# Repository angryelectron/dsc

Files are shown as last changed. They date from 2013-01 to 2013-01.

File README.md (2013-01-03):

The DSC is an Arduino-based differential solar controller.  Please visit
http://angryelectron.com/projects/dsc for more information.

Here you will find Eagle project files for the schematic and PCB, the DSC
firmware (Arduino sketch), a Google Gadget, and some Bash scripts that can be
used for monitoring.

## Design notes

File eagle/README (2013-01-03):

This is a CadSoft Eagle project for the DSC schematic capture and PCB layout. 

Set your Eagle project directory to this one for easy access to projects,
libraries, scripts, and design rules within the Eagle IDE.

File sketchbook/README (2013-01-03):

This is the firmware (Arduino sketch) for the DSC controller. Please see
http://angryelectron.com/projects/dsc for more information.

Set your Arduino IDE Sketchbook directory to this one to automatically include
the dependent libraries (DallasTemperature and OneWire), if you don't have them
installed elsewhere.

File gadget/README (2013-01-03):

This is a Google Gadget for displaying the output temperatures of the DSC.

Place gsolar.xml and screenshot.png on a webserver and update the URLS in
gsolar.xml to match.  Data for the gadget is taken from 'solar.xml', which is
produced by the dsc-monitor.sh script.

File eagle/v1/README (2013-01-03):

These are the Gerber files that were uploaded to BatchPCB to create the DSC
PCB.  View it here: https://batchpcb.com/pcbs/27415

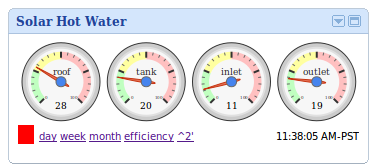
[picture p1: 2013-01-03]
gadget/screenshot.png

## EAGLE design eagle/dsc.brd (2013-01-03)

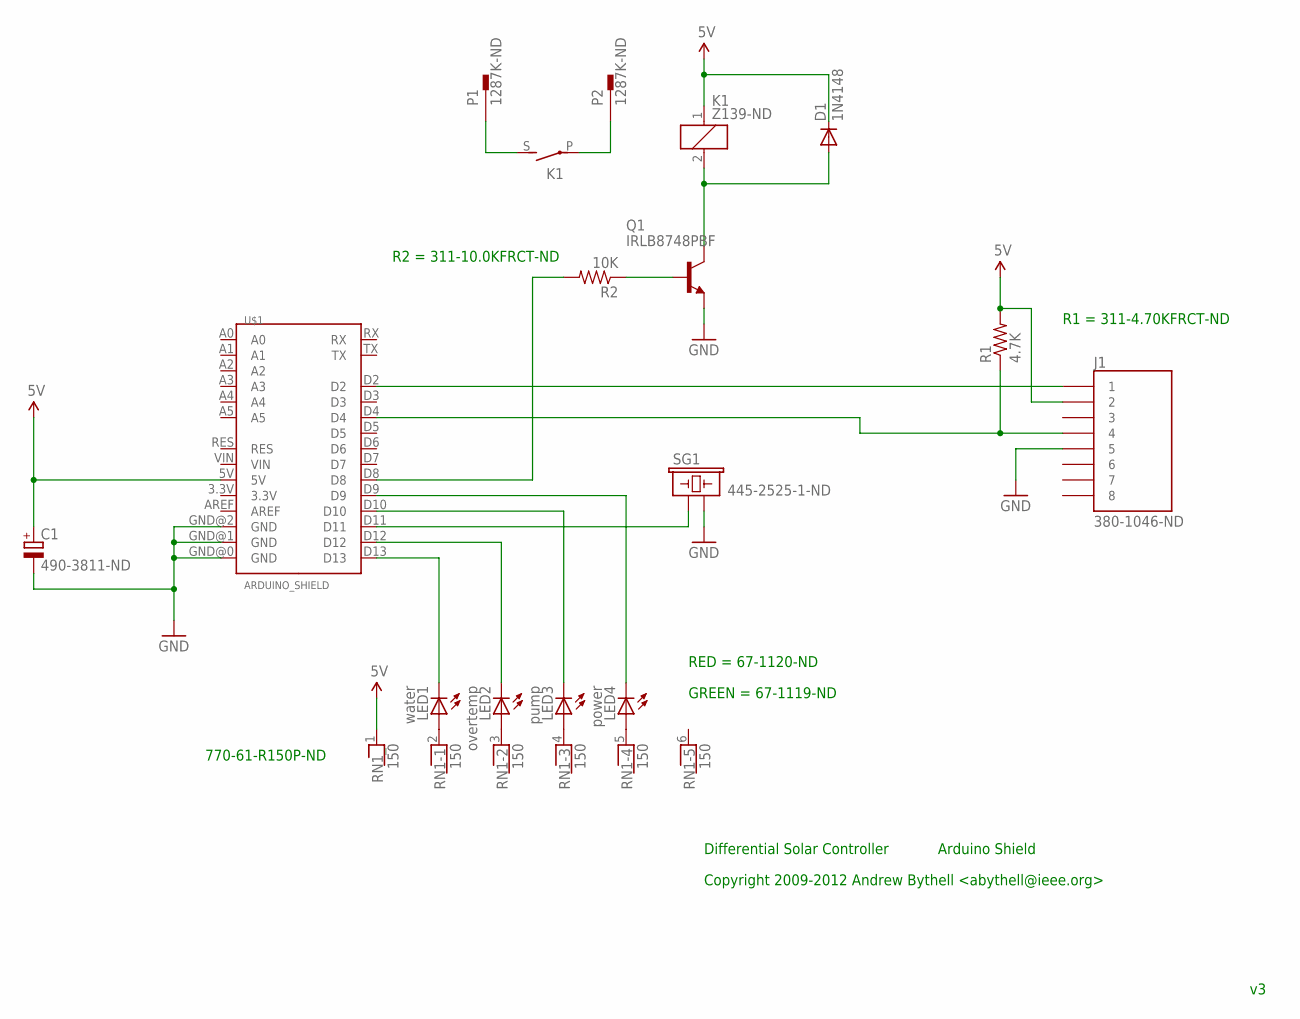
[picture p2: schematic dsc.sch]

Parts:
C1: 490-3811-ND; E3,5-8
D1: 1N4148; DO35-10
J1: 380-1046-ND; RJ45-8
K1: Z139-ND; G2RA
LED1: water; LED5MM
LED2: overtemp; LED5MM
LED3: pump; LED5MM
LED4: power; LED5MM
P1, P2: 1287K-ND; F061.100
Q1: IRLB8748PBF; TO18
R1: 4.7K; 1206
R2: 10K; 1206
RN1: 150; RN-6
SG1: 445-2525-1-ND; BUZZER-12MM-AB
U$1: ARDUINO_SHIELD; DUEMILANOVE_SHIELD

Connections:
5V: C1.+, D1.C, J1.2, K1.1, R1.2, RN1.1, U$1.5V
ERASE: J1.4, R1.1, U$1.D4
GND: C1.-, J1.5, Q1.1 (E), SG1.- (2), U$1.GND@0 (GND), U$1.GND@1 (GND), U$1.GND@2 (GND)
unnamed: Q1.2 (B), R2.1
unnamed: R2.2, U$1.D8
unnamed: D1.A, K1.2, Q1.3 (C)
unnamed: LED1.A, RN1.2
unnamed: LED2.A, RN1.3
unnamed: LED3.A, RN1.4
unnamed: LED4.A, RN1.5
unnamed: LED1.K (C), U$1.D13
unnamed: LED2.K (C), U$1.D12
unnamed: LED3.K (C), U$1.D10
unnamed: LED4.K (C), U$1.D9
unnamed: SG1.+ (1), U$1.D11
unnamed: K1.S, P1.A1, P1.A2
unnamed: K1.P, P2.A1, P2.A2
unnamed: J1.1, U$1.D2

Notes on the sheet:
Differential Solar Controller
Arduino Shield
770-61-R150P-ND
RED = 67-1120-ND
GREEN = 67-1119-ND
R1 = 311-4.70KFRCT-ND
R2 = 311-10.0KFRCT-ND
Copyright 2009-2012 Andrew Bythell <abythell@ieee.org>

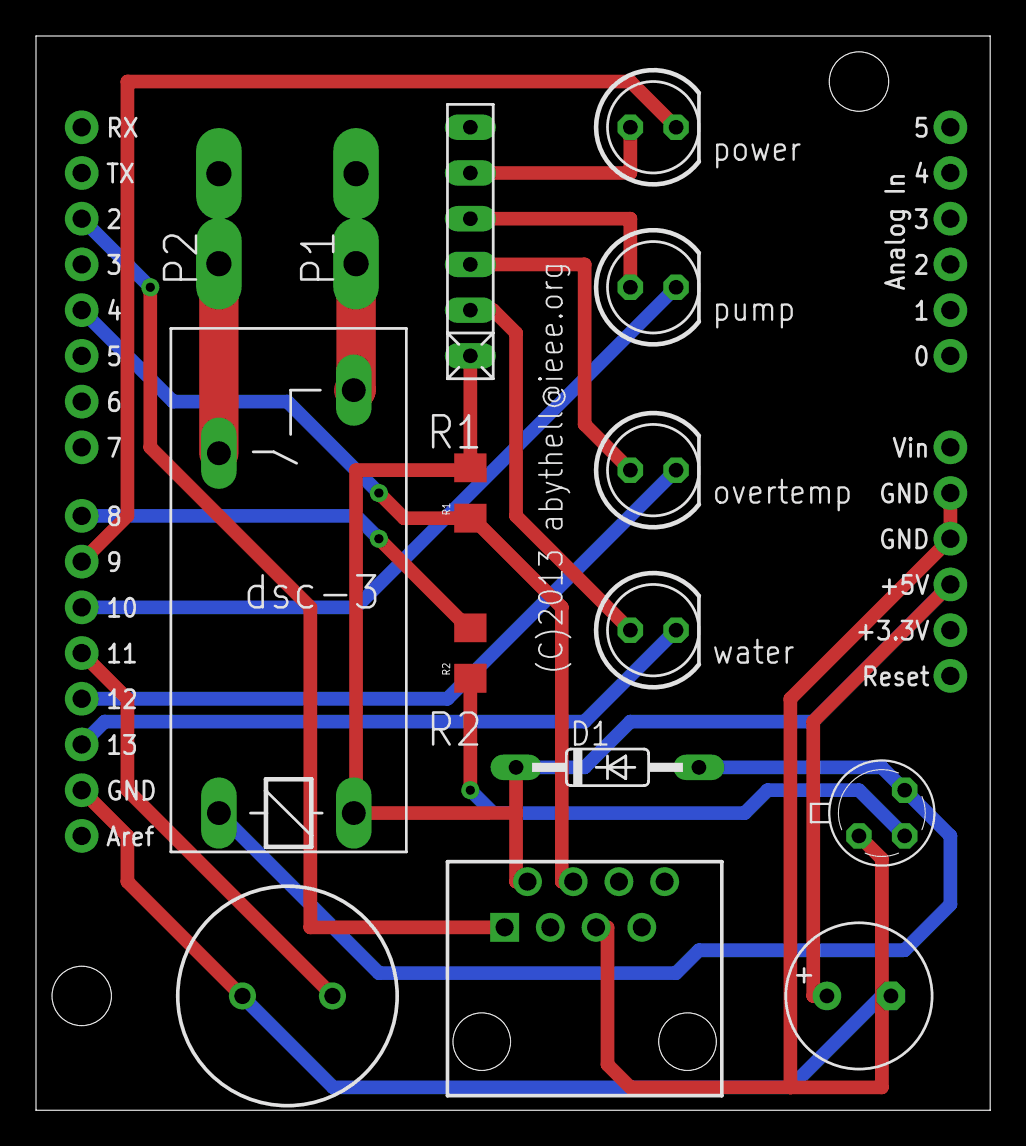
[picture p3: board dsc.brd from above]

Board: 2 copper layers, 53.0 x 59.7 mm, 16 parts (0 on the bottom side), 18 nets.

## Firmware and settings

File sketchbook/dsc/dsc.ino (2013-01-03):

/*
  Differential Solar Controller for Arduino 1.0
  Copyright 2009-2012 Andrew Bythell <abythell@ieee.org>

  This sketch depends on the Dallas Temperature Control Library (milesburton.com/Dallas_Temperature_Control_Library)
  version 3.7.2, and the OneWire 2 Library (pjrc.com/teensy/td_libs_OneWire.html) version 2.1.

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
  You should have received a copy of the GNU General Public License
  along with this program.  If not, see <http://www.gnu.org/licenses/>.
*/

#include <OneWire.h>
#include <DallasTemperature.h>
#include "dsc.h"

/*
 * Setup
 */
void setup(void) 
{
  	pinMode(PUMP_LED, OUTPUT);
        pinMode(PUMP_RELAY, OUTPUT);
	pinMode(POWER_LED, OUTPUT);
	pinMode(OVERTEMP_LED, OUTPUT);
	pinMode(WATER_LED, OUTPUT);
	pinMode(ALARM_PIN, OUTPUT);
	pinMode(WATER_SENSOR, INPUT);

	Serial.begin(9600);
        sensors.begin();
	POWER_ON;
        PUMP_OFF;
	OVERTEMP_OFF;
	ALARM_OFF;
	FAULT_OFF;
	WATER_OFF;
}

/*
 * Check for Low Water Level Condition
 */
void CheckWaterLevel()
{
	if (WATER_LOW)
	{
                PUMP_OFF;
		WATER_ON;
		state = LOWWATER_STATE; 
	}
}

/*
 * Stop State
 */
void StopState()
{
	if (sensors.getTempC(roofSensor) >= sensors.getTempC(tankSensor) + DELTA_ON)
	{
		PUMP_ON;
		state = RUN_STATE;
	}
}

/*
 * Run State
 */
void RunState()
{
	if (sensors.getTempC(tankSensor) >= HIGHTEMP_LIMIT)
	{
		PUMP_OFF;
		OVERTEMP_ON;
		state = OVERTEMP_STATE;
	}
	else if (sensors.getTempC(tankSensor) + DELTA_OFF >= sensors.getTempC(roofSensor))
	{
		PUMP_OFF;
		state = STOP_STATE;  
	}
}

/*
 * Over Temperature State
 */
void OverTempState()
{
	if ((sensors.getTempC(tankSensor) + DELTA_OFF >= sensors.getTempC(roofSensor))
          || (sensors.getTempC(tankSensor) <= OVERTEMP_LIMIT))
	{
		PUMP_OFF;
                OVERTEMP_OFF;
		state = STOP_STATE;  
	}
}

/*
 * Low Water State - Remain in Low Water State until the level is topped up.
 */
void LowWaterState()
{
	if (!WATER_LOW)
	{
		WATER_OFF;
		state = STOP_STATE;
	}
}

/*
 * Print Status to serial port for data logging
 */
void PrintStatus()
{
	uint8_t roofTemp = sensors.getTempC(roofSensor);
	uint8_t tankTemp = sensors.getTempC(tankSensor);
	uint8_t inletTemp = sensors.getTempC(inletSensor);
	uint8_t outletTemp = sensors.getTempC(outletSensor);
	char ascii[10];
	sprintf(ascii, "%02x %02x %02x %02x %02x", state, roofTemp, tankTemp, inletTemp, outletTemp);
	Serial.println(ascii);
}

/*
 * Loop
 */
void loop(void) 
{
    sensors.requestTemperatures();
    
    /*
     * Wait for temperature conversion to complete
     */
    delay(1000);
    
    CheckWaterLevel();
    switch(state)
    {
	case STOP_STATE:
		StopState();
		break;
	case RUN_STATE:
		RunState();
		break;
	case OVERTEMP_STATE:
		OverTempState();
		break;
	case LOWWATER_STATE:
		LowWaterState();
		break;
	default:
                break;
    } 
    PrintStatus();
}

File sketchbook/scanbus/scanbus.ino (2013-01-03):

/*
 * 1-wire Thermometer bus scanner
 * (C) 2012 Andrew Bythell <abythell@ieee.org>
 *
 * Scans the 1-wire bus and displays the addresses
 * of all 1-wire thermometers found.  The addresses can then be entered
 * into the DSC sketch.
 *
 * This is a stripped-down version of the "Multiple" example supplied with the
 * DallasTemperature library.
 */

#include <OneWire.h>
#include <DallasTemperature.h>

#define ONE_WIRE_BUS 4 /* the io pin connected to the 1-wire data line */

OneWire oneWire(ONE_WIRE_BUS); 
DallasTemperature sensors(&oneWire);

// arrays to hold device addresses
DeviceAddress inlet, outlet, roof, tank;

void setup(void)
{
  Serial.begin(9600);
  sensors.begin();

  Serial.print(sensors.getDeviceCount(), DEC);
  Serial.println("devices.");

  DeviceAddress thermometer;
  for (int i=0; i< sensors.getDeviceCount(); i++) {
    sensors.getAddress(thermometer,i);
    printData(thermometer);
  }
  
}

// function to print a device address
void printAddress(DeviceAddress deviceAddress)
{
  for (uint8_t i = 0; i < 8; i++)
  {
    // zero pad the address if necessary
    if (deviceAddress[i] < 16) Serial.print("0");
    Serial.print(deviceAddress[i], HEX);
  }
}

// function to print the temperature for a device
void printTemperature(DeviceAddress deviceAddress)
{
  float tempC = sensors.getTempC(deviceAddress);
  Serial.print("Temp C: ");
  Serial.print(tempC);
  Serial.print(" Temp F: ");
  Serial.print(DallasTemperature::toFahrenheit(tempC));
}

// main function to print information about a device
void printData(DeviceAddress deviceAddress)
{
  Serial.print("Device Address: ");
  printAddress(deviceAddress);
  Serial.print(" ");
  printTemperature(deviceAddress);
  Serial.println();
}

void loop(void)
{ 
  sensors.requestTemperatures();
  delay(100000);
}

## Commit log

2013-01-03 initial import
    [dsc.brd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]
2013-01-03 Replaced quickfit terminals with updated part - old part was causing DRC errors. Project updated for Eagle 6.3.
    [dsc.brd, dsc.sch]

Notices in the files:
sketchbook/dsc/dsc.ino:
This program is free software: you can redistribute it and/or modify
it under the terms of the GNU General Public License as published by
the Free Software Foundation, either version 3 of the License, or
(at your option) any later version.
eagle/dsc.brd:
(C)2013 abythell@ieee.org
